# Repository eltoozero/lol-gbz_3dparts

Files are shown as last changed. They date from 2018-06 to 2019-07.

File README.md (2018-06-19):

# Gameboy Zero SCAD 3D prints

This is the SCAD source code for my components for the GBZ project, specifically the Kite's Circuit Sword version.

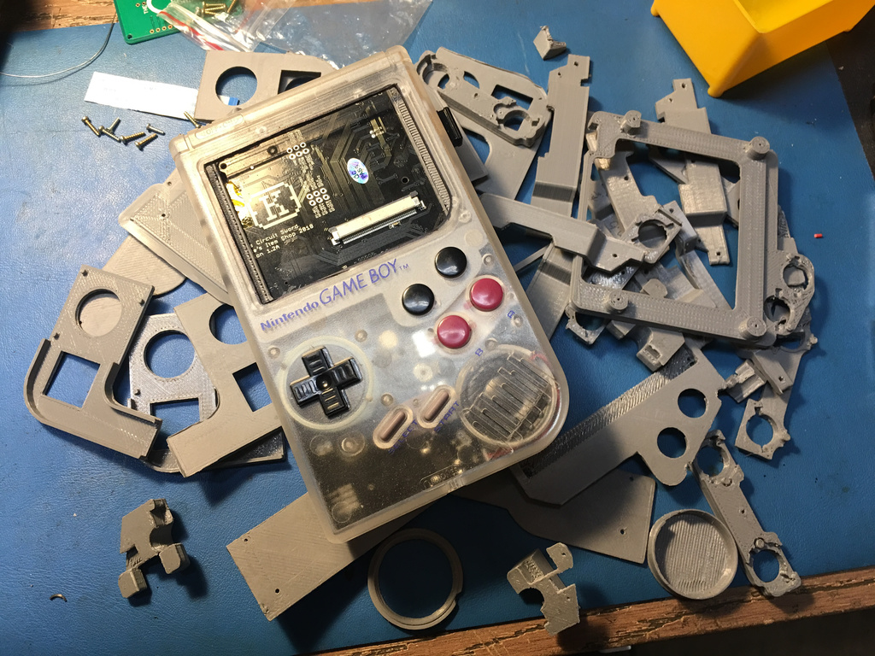
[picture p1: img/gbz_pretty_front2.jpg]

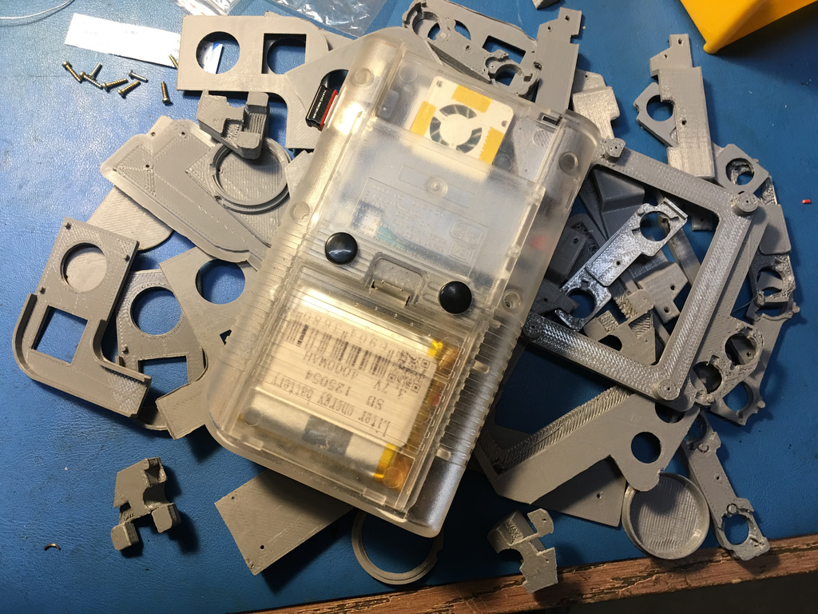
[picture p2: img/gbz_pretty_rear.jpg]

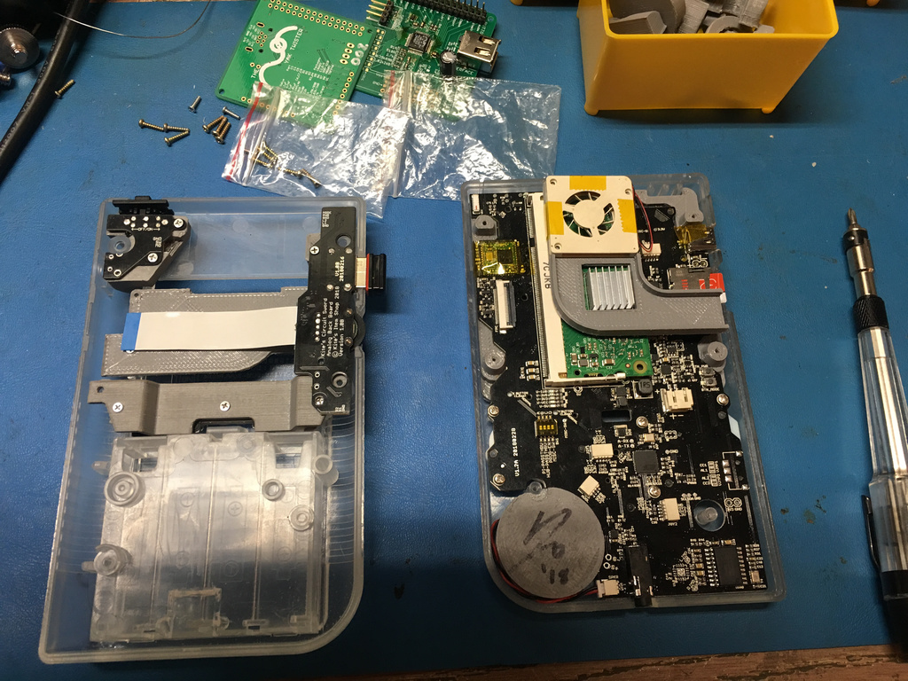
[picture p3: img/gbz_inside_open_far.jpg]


## Notes on SCAD files
I design stuff in SCAD, so my designs are all naturally "parametric" source code and thus can be iterated and modified using the same CSG logic from which they are produced: numeric translations and rotations, intersections, unions and differences of basic 2d and 3d primitives to produce a final "solid" object STL file which is output to the slicer for production on a 3D printer.

It's not going to help anyone to pull these into normal CAD software and make changes, if you want to "help", learn SCAD and fork the source; witness the [Genealogy of the "Greg's Wade's Geared Extruder](https://reprap.org/wiki/Genealogy_/_Archeology_of_the_Greg%27s_Wade%27s_Geared_Extruder) to see what happens when a quality SCAD design can flourish as source code.

## LCD Bracket
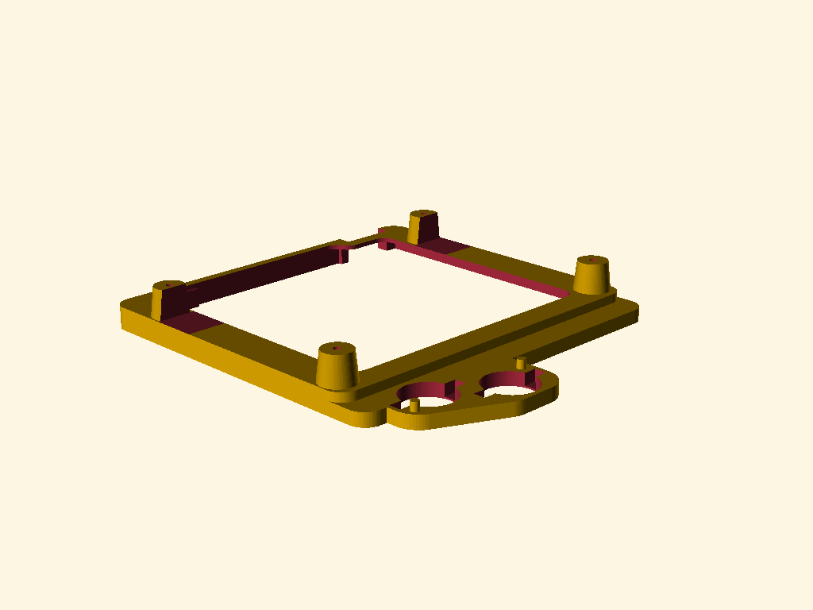
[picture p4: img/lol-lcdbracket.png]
LCD Bracket Image

There were some contours that didn't jive with me, and since I'm doing a clear build I desired more control over the final product, this one was pretty easy and only took two prototypes to get a functional part I was satisfied with.
 - Needs the other two buttons added, should be trivial, I only wanted 4 on my build.

## Back Button Bracket
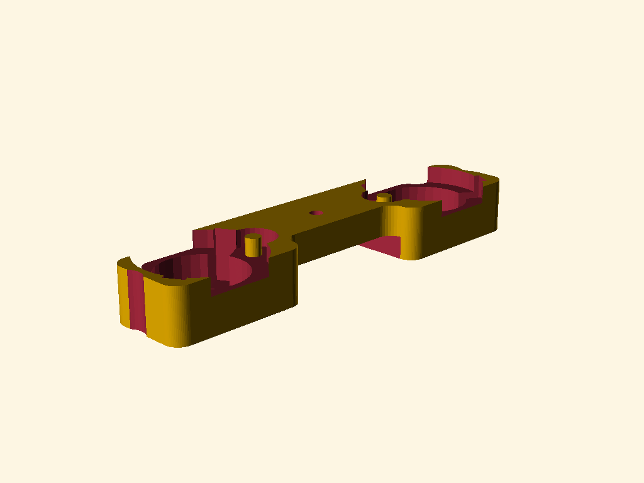
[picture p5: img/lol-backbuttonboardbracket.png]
Back Button Bracket Image

I actually emailed Kite for some info on the components the pcb was designed around that wasn't in the wiki, once it was clear it's not really a solved problem how this thing is installed in the case, I got to work. This took maybe a dozen revisions to get right, in the end it functions glue-less using the support bracket that also supports the back board.
 - Needs additional versions for 4-button and tact switch configs, I need reference parts to do this.

## Back Button Support
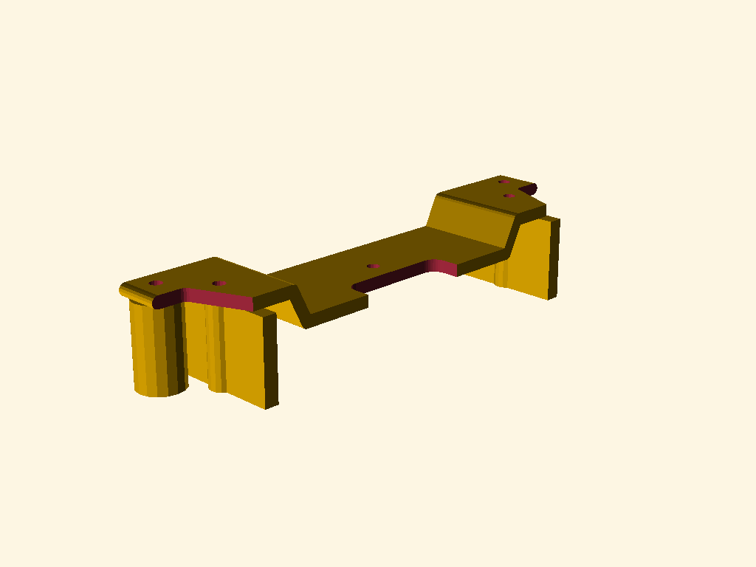
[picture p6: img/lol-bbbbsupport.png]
Back Button Support Image

This one was tricky, and I'm the least satisfied with this design aesthetically, but it prints well and functions for it's purpose, also keeps the entire cartridge slot intact and unmodified.
 - Make it look less crappy.
 - Needs relief for wiring.

## Speaker Cover
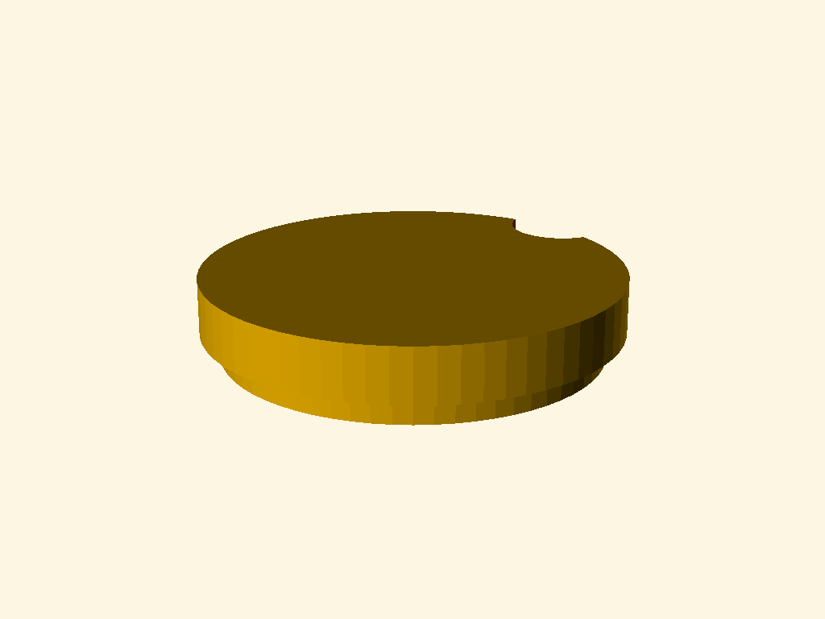
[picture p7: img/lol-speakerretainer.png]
Speaker Cover Image

Simple, I just didn't like the concept of gluing the speaker, and the tolerances are correct that this just press fits and stays snug once the case is closed.

## Power Board Support
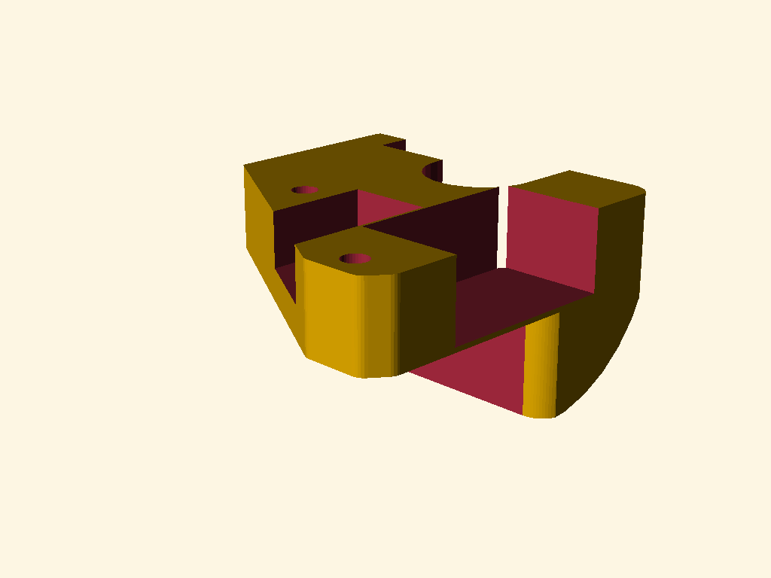
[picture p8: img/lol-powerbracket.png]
Power Board Support Image

Different approach than HoolyHoo, single part solution.

## Back Board Support
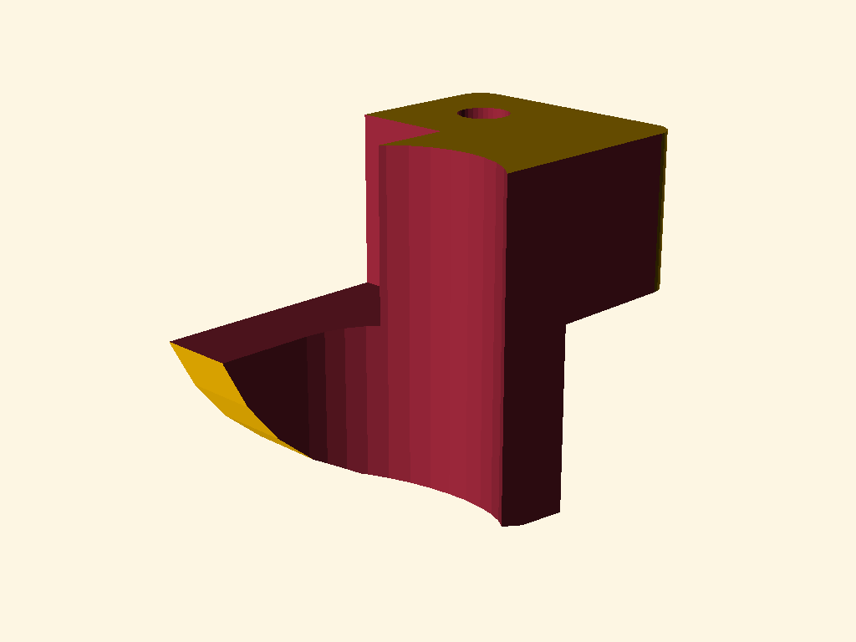
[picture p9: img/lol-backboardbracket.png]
Back Board Support Image

Hadn't seen this one and it's a basic variation of the otherwise much more complicated: Power Board Support.

## Cartridge Plate & Fan Duct
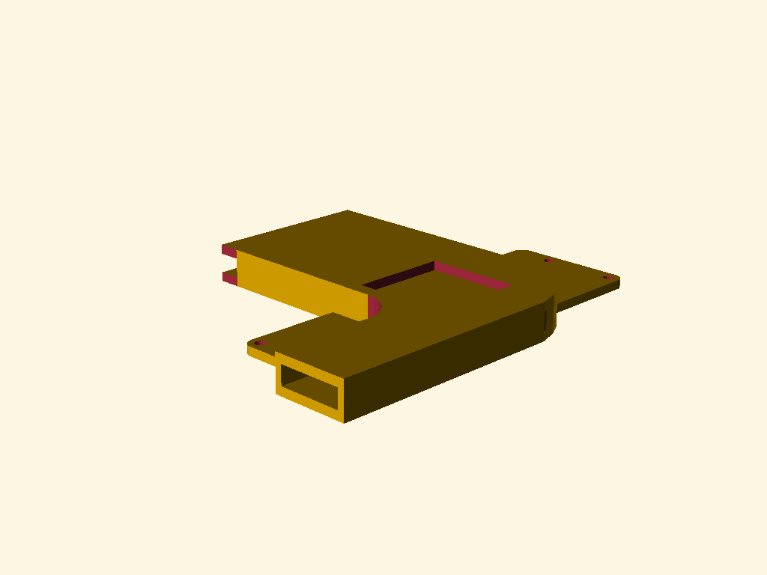
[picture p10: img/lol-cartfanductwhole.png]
Fan Duct Image

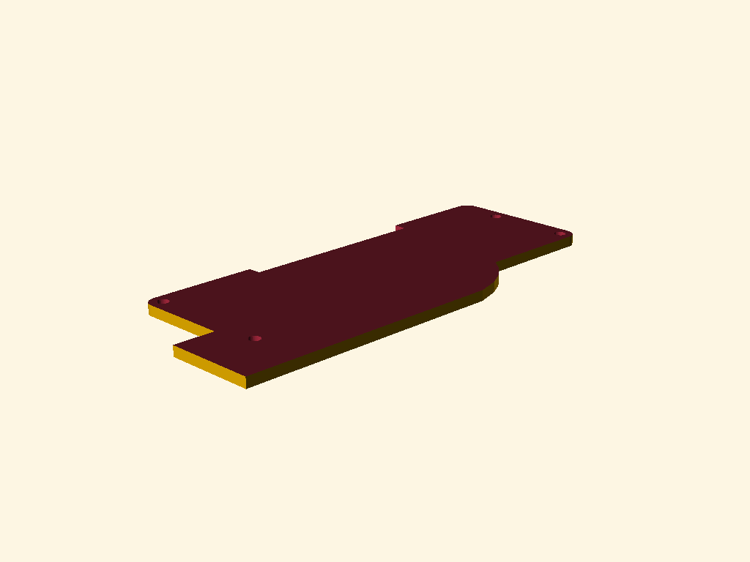
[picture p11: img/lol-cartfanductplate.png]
Fan Duct Plate Image

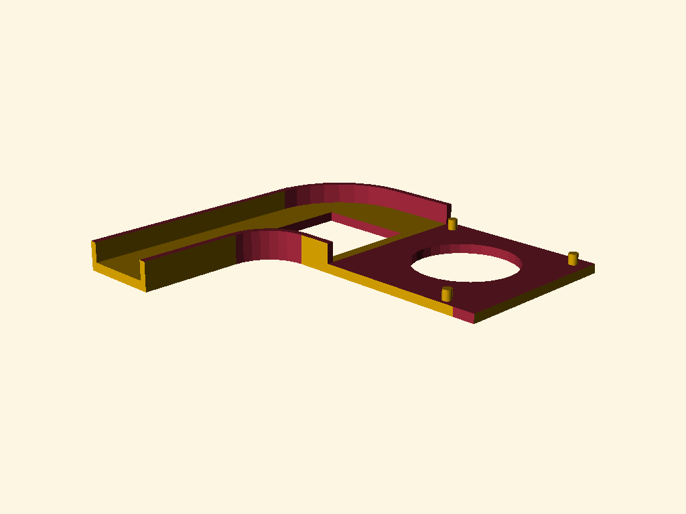
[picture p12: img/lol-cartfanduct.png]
Fan Duct Image

This guy took some thought and effort, and only functions as cleanly as it turned out due to luck, the tolerances are super tight. Kapton or double-sided tape the fan to the support bracket, then use a double stack of 3M VHB to hold the duct in place on the CM3.
 - I'm "exhausted" working on this one.
 - There's probably some optimization potential though.

I'll be selling these parts on eBay and sudomod once I get the extruder upgraded on my "other" 3D printer, these are fine for personal use but please don't sell them unless I'm not, further you are free and encouraged to modify these designs as long as I retain credit and am not artificially restricted from production and sale of designs based on my source code.

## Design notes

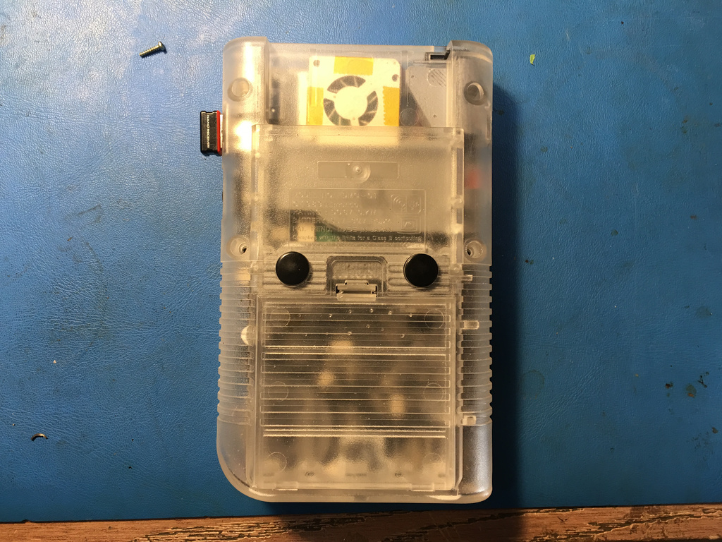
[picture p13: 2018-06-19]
img/gbz_closed_rear.jpg

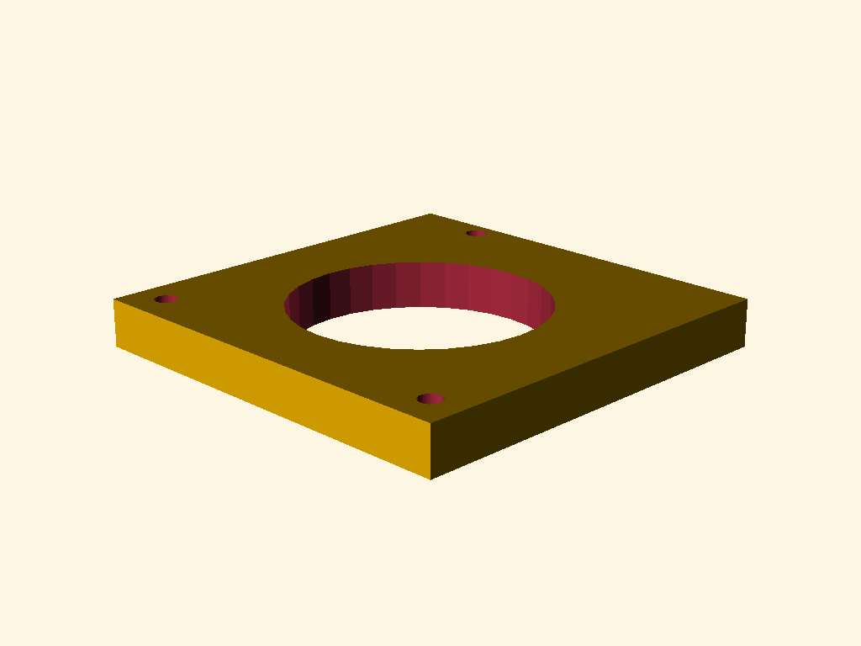
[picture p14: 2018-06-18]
img/lol-fanmockup.png

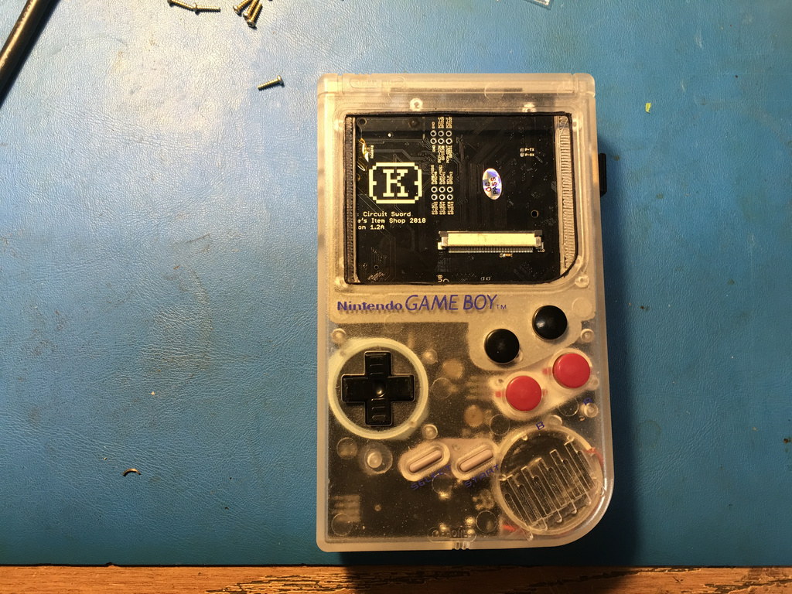
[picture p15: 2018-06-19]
img/gbz_closed_front.jpg

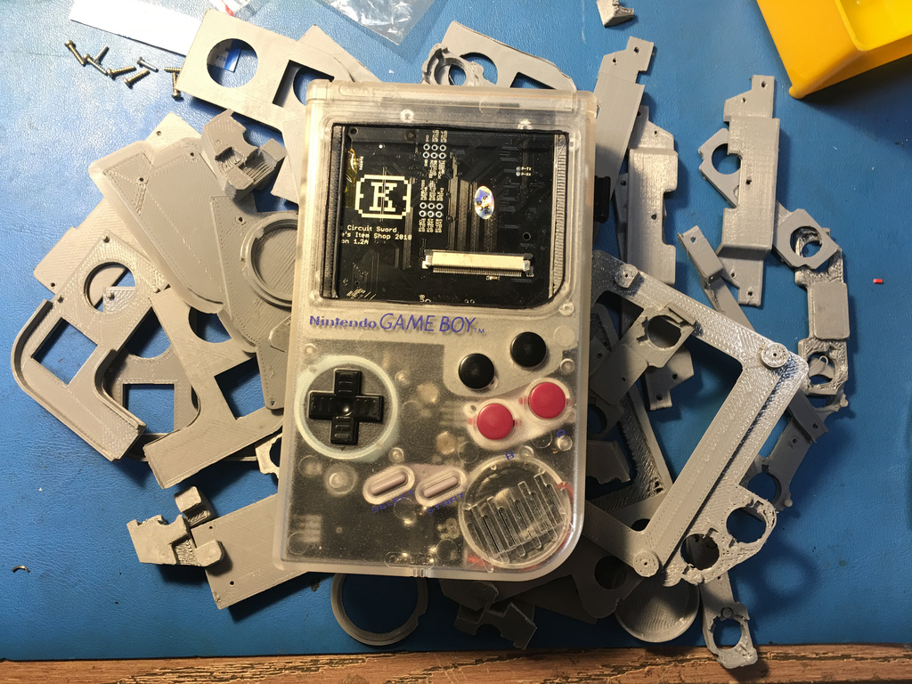
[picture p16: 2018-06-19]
img/gbz_pretty_front.jpg

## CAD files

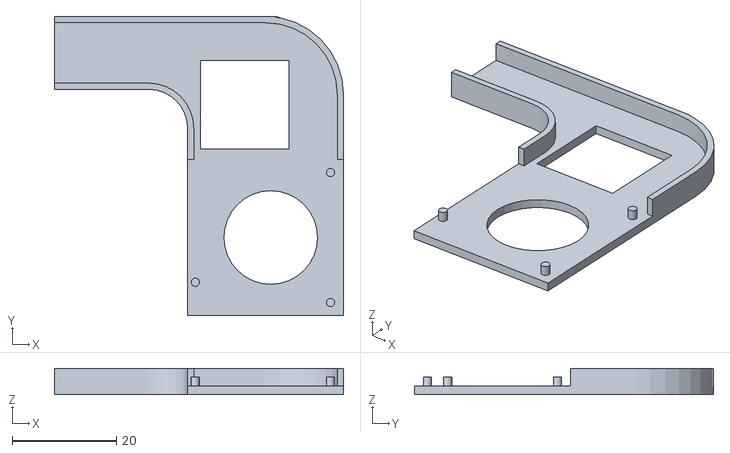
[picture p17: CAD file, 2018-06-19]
stls/lol-cartfanductwhole.stl
55.6 x 57.5 x 5.00

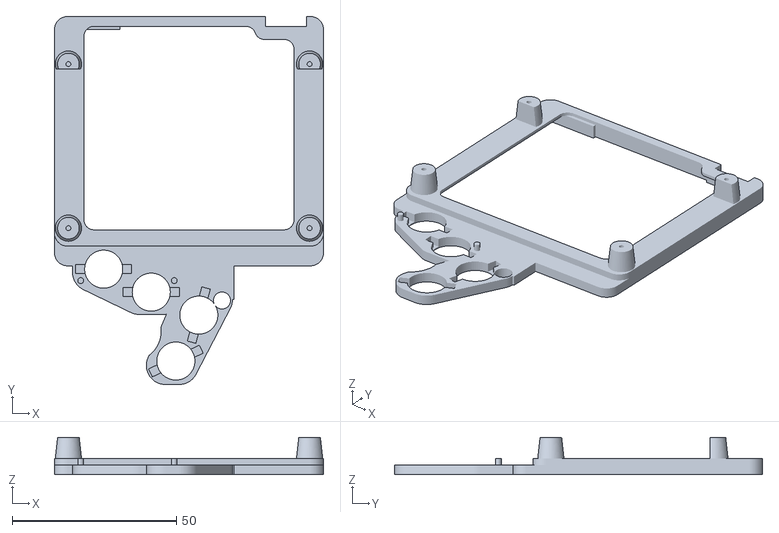
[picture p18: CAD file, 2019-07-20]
stls/lol-lcdbracket_6button.stl
82.0 x 112.2 x 11.4

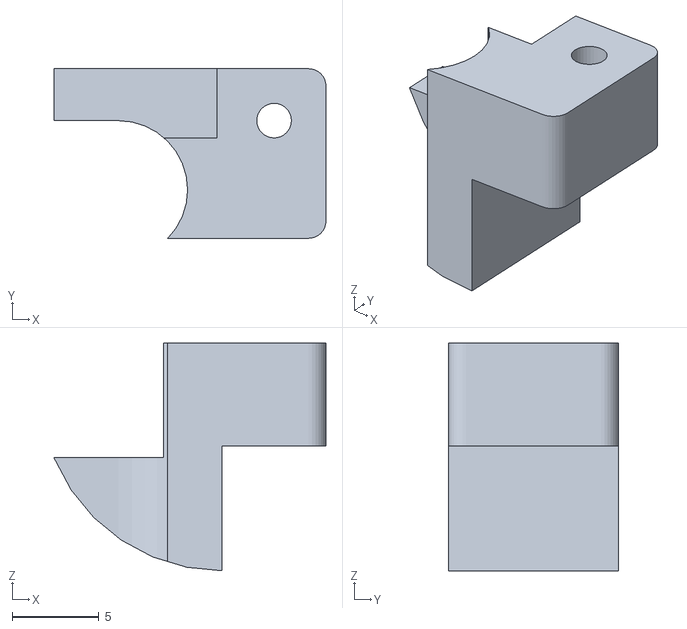
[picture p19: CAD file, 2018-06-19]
stls/lol-backboardbracket.stl
15.7 x 9.80 x 13.2

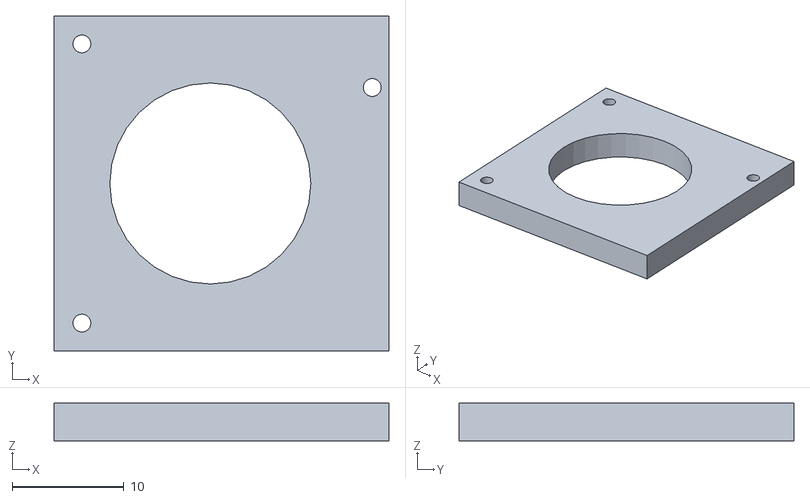
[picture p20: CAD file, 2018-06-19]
stls/lol-fanmockup.stl
30.0 x 30.0 x 3.40

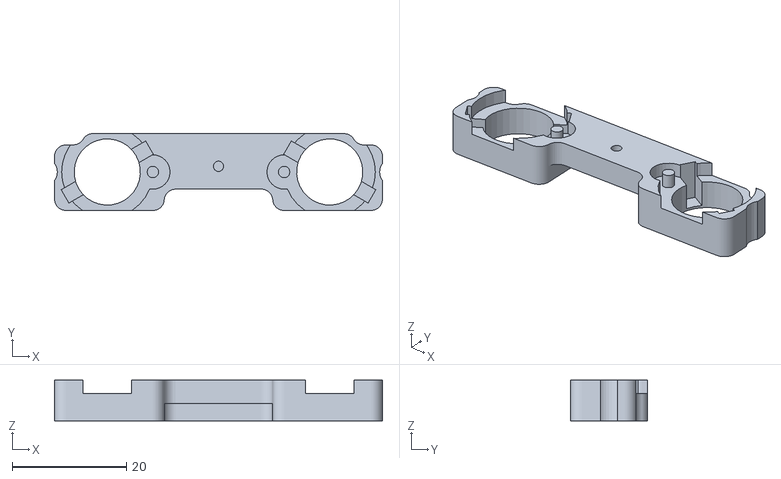
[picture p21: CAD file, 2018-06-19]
stls/lol-backbuttonboardbracket.stl
57.5 x 13.5 x 7.10

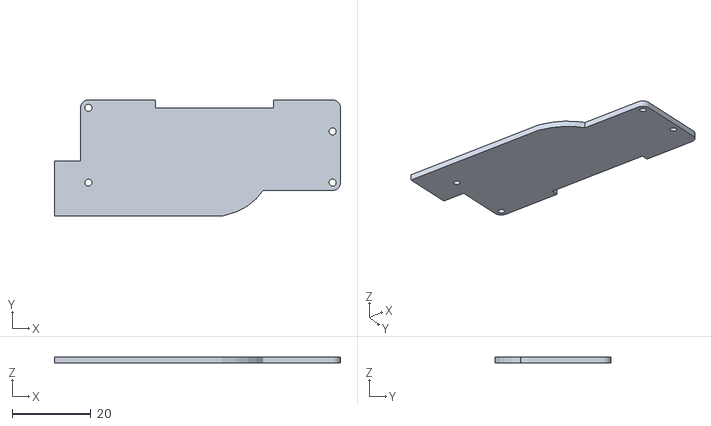
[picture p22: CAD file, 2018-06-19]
stls/lol-cartfanductplate.stl
72.6 x 29.5 x 1.60

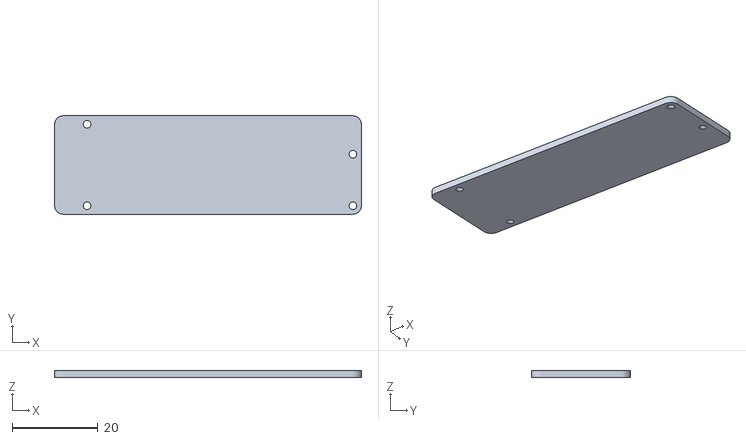
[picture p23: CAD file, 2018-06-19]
stls/lol-cartfanplate.stl
71.6 x 23.0 x 1.60

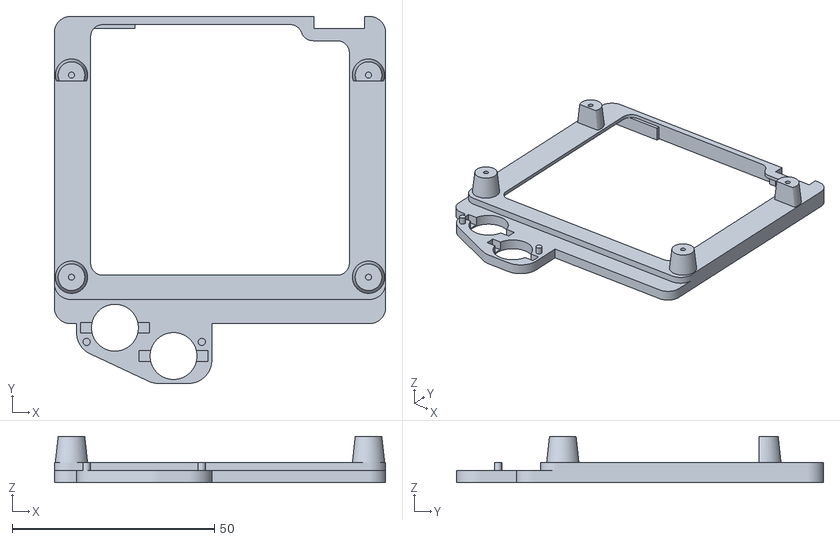
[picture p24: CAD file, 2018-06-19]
stls/lol-lcdbracket.stl
82.0 x 90.8 x 11.4

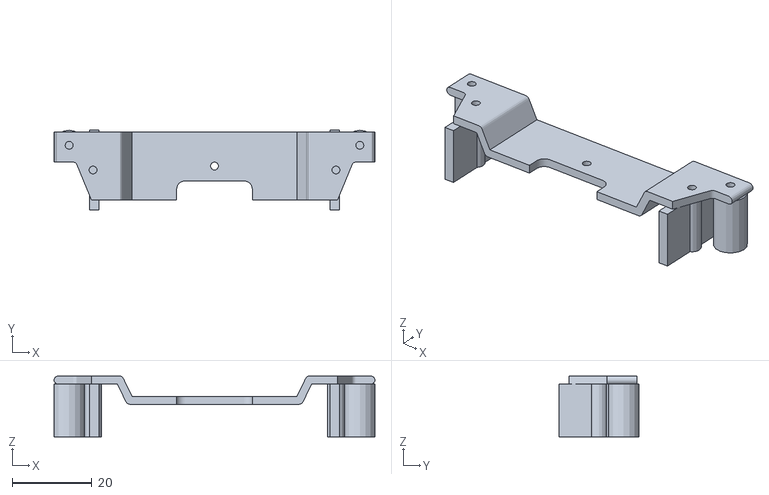
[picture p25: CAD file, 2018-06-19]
stls/lol-bbbbsupport.stl
80.6 x 20.0 x 15.3

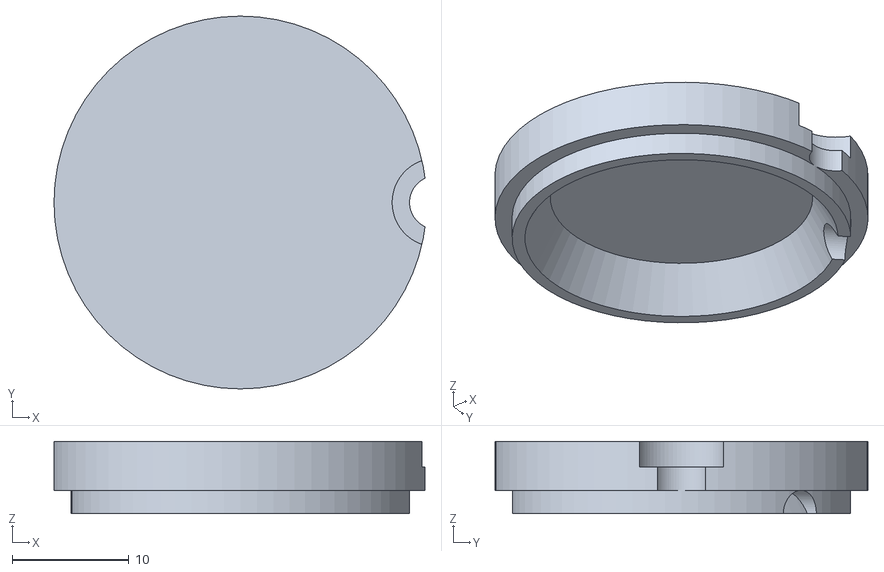
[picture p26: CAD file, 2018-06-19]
stls/lol-speakerretainer.stl
31.8 x 32.0 x 6.20

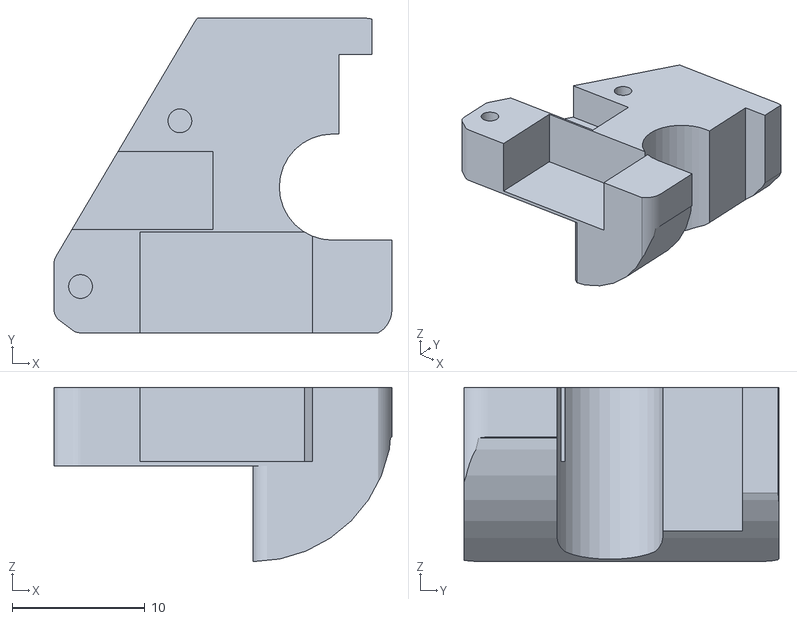
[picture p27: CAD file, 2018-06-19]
stls/lol-powerbracket.stl
25.5 x 23.8 x 13.2

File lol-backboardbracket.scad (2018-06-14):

//lol here's a power/mode button support

//notes from mvp print:
//-cut entire front face for mode button
//-add 1mm fudge room around parts.
//-add a 1mm z depth to connectors
//-remove 2.2mm from the extension "height".

//notes from mvp2 print:
//-still need 2.2mm extra thickness on support.

$fn=32;

// hclearance left of cartridge area inside shell
// measured 10.75mm

pcbclearance=1.1;
hclearance=10.5;
vclearance=14.25;
stackclearance=7.2;

supportplatethickness=vclearance-pcbclearance-stackclearance;
vsupport=(supportplatethickness+hclearance)-vclearance;
echo(supportplatethickness);
echo(vsupport);

//translate([-modex,-10,-vclearance])
//color("blue") cube([modex,modey,vclearance]);
//
//translate([-modex,modey-10,-vclearance])
//color("red") cube([10,10,stackclearance]);

// peg keepout
//D measured 7.58mm
pegD=8;
//Inset measured ~ 4.88mm
pegI=4.5;
//Y
pegY=11;

//mode board
// H
modey=24;
// W
modex=25.5;
// no mount
modexnoflag=21;

noflag=true;

//mode button itself
// H
mbuttx=4;
// W
mbutty=6.5;
// D
mbuttz=vclearance;

//face clearance
facecw=10.5;
facech=7;

// Power Switch
//H
pswz=5.6;
//W measured 12.69mm
pswx=13;
//D 
pswy=7.5;
//Offset
mswo=6;

//Connector
//H
mconz=3.7;
//W
mconx=4.4;
//D
mcony=5.4+.5;
//X Offset
mconox=13.5;
//Y Offset
mconoy=7.8;

//Mounting holes
md=1.8;
//Top X
tx=23.5;
//Top Y
ty=3.5;
//Bot X
bx=16;
//Bot Y
by=16;

//Back board mount hole

bbmx=9;
bbmy=4;

//Back board ports

usbx=10.2;
usby=14.6;
usbz=6.6;

swconx=4.4;
swcony=8.2;
swconz=3.2;

module usbcut() {
    translate([0,pegY+pegD/2-1,-usbz-pcbclearance])
    cube([usbx,usby,usbz]);
}

module swconcut() {
    translate([0,0,-swconz-pcbclearance-vclearance])
    cube([swconx+hclearance+3, swcony, swconz+vclearance]);
}

module backboard_mount() {
    translate([pegI+bbmx,pegY+bbmy,-vclearance])
    cylinder(d=2,h=vclearance);
}

//base_shape();

final_part();

//post placement
//translate([-hclearance,modey+3,-vclearance-pcbclearance])
//cylinder(d=2, h=vclearance);

module final_part() {

    intersection(){
difference() {
    base_shape();
    all_cuts();
    backboard_mount();
    swconcut();
    usbcut();
    //cheat
    translate([0,pegY+bbmy+3,0])
    swconcut();
    //base_block();
}
//        union(){
//        over_cut();
//        over_cut_low();
//        
//        }
    }
}

module base_shape() {
    union() {
        base_block();
        smooth_base();
        //support_tab();
    }
}

module over_cut(){
    translate([-modey/2-1,modex/2-1,-supportplatethickness-pcbclearance])
    cheese(modey+2, modey, supportplatethickness, 2);
}

module over_cut_low(){
    translate([-hclearance/2,modex/2-1,-(vclearance-supportplatethickness-pcbclearance)-supportplatethickness-pcbclearance])
    cheese(hclearance, modey, vclearance-supportplatethickness-pcbclearance, 2);
}


module smooth_base() {
    translate([0,0,-supportplatethickness-pcbclearance])
    hull() {
        
    //top left
//    translate([1,1,0])
//#    cylinder(d=2, h=supportplatethickness);

    //bottom left
//    translate([1,modey-1,0])
//    cylinder(d=2, h=supportplatethickness);

    //top left inside step
//    translate([-1-3,1,0])
//    cylinder(d=2, h=supportplatethickness);

    //bottom left inside step
    translate([0,pegY+bbmy+2,0])
    cylinder(d=2, h=supportplatethickness);

    //bottom left inset
    translate([pegI+bbmx,pegY+bbmy,0])
    cylinder(d=2, h=supportplatethickness);

    //bottom left inset
    translate([pegI+bbmx+2,pegY+bbmy+2,0])
    cylinder(d=2, h=supportplatethickness);

    translate([pegI+bbmx+2,swcony+1,0])
    cylinder(d=2, h=supportplatethickness);

    translate([0,swcony+1,0])
    #cylinder(d=2, h=supportplatethickness);

    //top right
    //translate([-modex+1,1,0])
    //cylinder(d=2, h=supportplatethickness);

    //top right new
//    translate([pegI+bbmx+2,1,0])
//    cylinder(d=2, h=supportplatethickness);
//    
    //top right inset
//    translate([-modex+2,1,0])
//    cylinder(d=2, h=supportplatethickness);


    //right 1st attempt
    //translate([-modex+1,pswy,0])
    //#cylinder(d=2, h=supportplatethickness);

    // bottom hole outlines
//    translate([-bx-1,by-pswy/2+2,0])
//    cylinder(d=2, h=supportplatethickness);
//
//    translate([-bx-1,by+pswy/2-2,0])
//    cylinder(d=2, h=supportplatethickness);

    // top hole outlines
//    translate([-tx-1,ty-pswy/2+2,0])
//    cylinder(d=2, h=supportplatethickness);
//
//    translate([-tx-1,ty+pswy/2-2,0])
//    cylinder(d=2, h=supportplatethickness);
        
    //bottom left
//    translate([-1,modey+3,supportplatethickness-3.75])
//    cylinder(d=2, h=3.75);
    //bottom left inside step
//    translate([-1-3,modey+3,0])
//    cylinder(d=2, h=supportplatethickness);

    }
} //end smooth_base module

module support_tab(){
    translate([0,0,-pcbclearance-supportplatethickness-1.2])
    hull() {
        //tab support
        translate([-hclearance,modey+3,0])
        cylinder(d=4, h=1.2);
        
        //bottom left
        translate([-1,modey-1,0])
        cylinder(d=2, h=1.2);
        
        //bottom left inset
        translate([-1-13,modey-1,0])
        cylinder(d=2, h=1.2);
    }
}

module all_cuts() {
    
//    difference() {
//
//    base_block();

    translate([pegI, pegY, -vclearance]){
        //peg clearance
        cylinder(d=pegD, h=vclearance);
        translate([-pegD,-pegD/2,0])
        //peg extension
        cube([pegD,pegD,vclearance]);
    }
        //mode button cut
//        translate([-mbuttx,modey-mbutty-3,-mbuttz-pcbclearance])
//        cube([mbuttx,mbutty,mbuttz]);

        //mode button face cut
        translate([0-1.5,modey-facecw,-facech-4])
        cube([mbuttx/2,facecw+1,facech+4]);

        //power switch
//        translate([-pswx-mswo,-1,-pswz-pcbclearance])
//        cube([pswx, pswy+pcbclearance, pswz]);

        //connector
//        translate([-mconx-mconox-10,mconoy,-mconz-pcbclearance])
//        cube([mconx+10, mcony, mconz+pcbclearance]);
    
        //connector thru
//      translate([-mconx-mconox-10,mconoy,-(vclearance-hclearance+1)])
//        #cube([mconx+10, mcony, vclearance-hclearance+1]);

        //Mounting holes
//        translate([-tx,ty,-supportplatethickness])
//        cylinder(h=supportplatethickness, d=md);
//        translate([-bx,by,-supportplatethickness])
//        cylinder(h=supportplatethickness, d=md);

        //post placement
        translate([-hclearance,modey+3,-vclearance-pcbclearance])
        cylinder(d=1.8, h=vclearance);

//    } // end difference 
} //end rough part


module base_block(){
    translate([hclearance,0,-vclearance+hclearance]) {
    union() {
        rotate([90,0,180])
        difference(){
            cylinder(h=modey, r=hclearance);

            translate([-hclearance,0,0])
            cube([hclearance*2,hclearance*2,modey]);

            translate([-hclearance*2,-hclearance,0])
            cube([hclearance*2,hclearance*2,modey]);
        }
        
        //base plate
//        translate([-modex+hclearance,0,0])
//        cube([modex, modey, vclearance-hclearance]);
//        translate([hclearance,0,0])
        }
    }
}
        

module cheese(x,y,z,r) {
linear_extrude(height=z) offset(-r) offset(r) offset(r) offset(-r)
    square([x,y], center=true);
}

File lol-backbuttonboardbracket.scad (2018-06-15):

$fn=32;

// DMG Rear Body Dimensions
// Above Battery Compartment

// Width measured 58mm 
OuterW=57.5;
// W
LatchW=19;
// Detpth measured .7mm
latchz=1;

//Silicone thickness
silz=2.3;
//Sil diameter
sild=16;

//side post -y from notch bottom
py=5;
// post diameter
pd=5; //measured 4mm, oversizing.

module post_removal() {
    for(x=[-OuterW/2-2:OuterW+4:OuterW/2+2]) {
        translate([x,0,0])
        cylinder(d=pd,h=ExtD+silz);
    }
}


module lil_peg() {
for(i=[-DualButtonSep/2+sild/2:DualButtonSep-sild:DualButtonSep/2-sild/2]) {
    translate([i,0,ExtD])
    cylinder(d=2,h=silz);
}
}
//sil_cut();
module sil_cut() {
for(i=[-DualButtonSep/2:DualButtonSep:DualButtonSep/2]) {
    translate([i,0,ExtD])
    cylinder(d=sild,h=silz);
}

for(i=[-DualButtonSep/2+sild/2:DualButtonSep-sild:DualButtonSep/2-sild/2]) {
    translate([i,0,ExtD])
    cylinder(d=6,h=silz);
}
}

module side_supports(){
    hull() {
        translate([OuterW/2-supd/2,-supd/2-.5,ExtD]){
    translate([0,NotchH/2-2,0])
    cylinder(d=supd, h=silz);
    translate([0,-NotchH/2+2,0])
    cylinder(d=supd, h=silz);
        }
    }
    hull() {
        translate([-OuterW/2+supd/2,-supd/2-.5,ExtD]){
    translate([0,NotchH/2-2,0])
    cylinder(d=supd, h=silz);
    translate([0,-NotchH/2+2,0])
    cylinder(d=supd, h=silz);
        }
    }

}

// H measured at 11.8mm
NotchH=11.5;
// Thickness measured 2.2mm
notchy=2;

// DMG Button Dimensions
// H
ButtonH=10;
// R
ButtonR=5.8;

// DMG Button Flag
// H
FlagH=ButtonH;
// W
FlagW=2.7;
// D
FlagD=5.5;

supd=1.2;

// Button Extension
// H
ExtH=14;
// W
ExtW=29.5;
// D
ExtD=3+1.8;
// Lip
ExtLip=6;

DualButtonSep=39;
//
//translate([-8.5-OuterW/2,18.1,-2])
//rotate([90,0,0])
//import("gbz_KiteBracket.stl");

module backbracketbody2d() {
    difference() {
    union(){
        translate([-OuterW/2,-NotchH/2,0])
        square([OuterW,NotchH]);
        translate([-48/2,NotchH/2])
        square([48,notchy]);
    }
    translate([-LatchW/2,-NotchH/2])
    square([LatchW, 3.75]);
    }
}

module backbracketbody() {
linear_extrude(height=ExtD+silz) offset(-2) offset(2) offset(2) offset(-2)backbracketbody2d();
}

//rotate([0,180,0])
final_part();
module final_part() {
    lil_peg();
    difference(){
    union() {
    //translate([-OuterW/2,-ExtH/2,0])
    //linear_extrude(height=ExtD) offset(2) offset(-2) square([OuterW,ExtH]);

    translate([0,-1,0])
    backbracketbody();
//    side_supports();

//    translate([0,2.75,ExtD])
    //#cube([LatchW, ExtH, latchz], center=true);
//    cheese(LatchW, ExtH-2.75, silz, 2);

//    translate([DualButtonSep/2,7.5,ExtD])    
//    cylinder(d=1.8, h=2.4);
//    translate([-DualButtonSep/2,7.5,ExtD])    
//    cylinder(d=1.8, h=2.4);
    }

    //translate([OuterW/2-10,0,0])
    translate([DualButtonSep/2,0,0])
    rotate([0,0,-30])
    dmgbutton();

    translate([-DualButtonSep/2,0,0])
    rotate([0,0,30])
    dmgbutton();
    post_removal();
    sil_cut();
    //translate([0,0,latchz/2])
    //cube([LatchW, ExtH, latchz], center=true);
    translate([0,-2.5,0])
    cheese(LatchW, ExtH, latchz*3, 2);

    //screw hole
    translate([0,1,4])
    cylinder(d=1.8,h=ExtD+silz);
    }
}

//Button
module dmgbutton(x,y) {
translate([x,y,0])    
    union() {
        cylinder(h=ButtonH, r=ButtonR); 
        translate([-ButtonR,0,FlagH/2+.4])
            cube([FlagD,FlagW,FlagH], center=true);
            translate([ButtonR,0,FlagH/2+.4])
            cube([FlagD,FlagW,FlagH], center=true);
    }
}

module cheese(x,y,z,r) {
linear_extrude(height=z) offset(-r) offset(r) offset(r) offset(-r)
    square([x,y], center=true);
}

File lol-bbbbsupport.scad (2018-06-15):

//lol-bbbbsupport

$fn=16;

//button board bracket clearance
bbcz=6.4;

//slot clearance
slcz=8.2;





// Mounting Posts Case
// Diameter
cmd=7.6;
// Height
cmz=13.3;
// OffsetY
cmoy=2.7+.5;
// OffsetX
cmox=74-1;
// Hole Diameter
cmhd=2;

// Mounting Posts PCB
// Diameter
pmd=4.2;
// Height
pmz=13.3;
// OffsetY
pmoy=-4+1;
// OffsetX
pmox=62-1;
// Hole Diameter
pmhd=2;


//Post Y Distance 
//12.6 - 4.2/2 - 7.6/2
//12.6 - 2.1 - 3.8
//12.6 - 5.9
// 6.7

// Width measured 58.5mm 
OuterW=58;
// W
LatchW=19;
// Detpth measured .7mm
LatchD=1;
NotchW=53;
NotchX=OuterW-NotchW;

latchcx=14;

// H measured at 11.8mm
notchh=11.5;
// Thickness measured 2.2mm
notcht=2.4;
notchy=3.75;

// Other Parameters
//main thickness
pt=2;

//post offset y
poy=6.7;

//overall y dimension
oy=17;

//translate([0,3,0])
//mounting_posts();
//walls();
//translate([0,0,0])
//import("lol-backbuttonboardbracket.stl");

module walls() {
for (x=[-OuterW/2-notcht/2:OuterW+notcht:OuterW/2+notcht/2])
translate([x,0,pmz/2])
cube([notcht, 20, pmz], center=true);
}

module connector_cut() {
    hull() {
    translate([cmox/2+10,0,0])
    cylinder(d=2,h=pmz+pt);
    translate([cmox/2-1,0,0])
    cylinder(d=2,h=pmz+pt);
    translate([cmox/2-notchh/2,-notchh,0])
    cylinder(d=2,h=pmz+pt);
    translate([cmox/2+10,-notchh,0])
    cylinder(d=2,h=pmz+pt);
    }
}


module notch_cut2() {
    translate([0,-notchy*2,slcz])
    cheese(LatchW,3.75*2,pt,2);

}
//notch cut
//notch_cut();
module notch_cut(){
    hull(){
    
    translate([0,-oy/2+notchy/2,0]){
        translate([-latchcx/2,0,0])
        cylinder(d=notchy, h=pmz);
        translate([latchcx/2,0,0])
        cylinder(d=notchy, h=pmz);
    }
    translate([0,-oy/2-notchy/2,0]){
        translate([-LatchW/2,0,0])
        cylinder(d=notchy, h=pmz);
        translate([LatchW/2,0,0])
        cylinder(d=notchy, h=pmz);
    }

    }
}

module screw_cut(){
translate([0,1,0])
cylinder(d=2, h=pmz);
//    hull(){
//    
//    translate([0,-oy/2+notchy/2+4,0]){
//        translate([-latchcx/2+4,0,0])
//        cylinder(d=notchy, h=pmz);
//        translate([latchcx/2-4,0,0])
//        cylinder(d=notchy, h=pmz);
//    }
//    translate([0,-oy/2-notchy/2+4,0]){
//        translate([-LatchW/2+4,0,0])
//        cylinder(d=notchy, h=pmz);
//        translate([LatchW/2-4,0,0])
//        cylinder(d=notchy, h=pmz);
//    }
//
//    }
}


//mounting post stand ins
module mounting_posts() {
    //PCB Mount posts
    //left
    translate([-pmox/2, pmoy, 0])
    cylinder(d=pmd, h=pmz);
    //right
    translate([pmox/2, pmoy, 0])
    cylinder(d=pmd, h=pmz);

    //Case Mount posts
    //left
    translate([-cmox/2, cmoy, 0])
    cylinder(d=cmd, h=cmz);
    //right
    translate([cmox/2, cmoy, 0])
    cylinder(d=cmd, h=cmz);
}

//mounting_holes();
module mounting_holes() {
    //PCB Mount posts
    //left
    translate([-pmox/2, pmoy, 0])
    cylinder(d=pmhd, h=pmz+pt);
    //right
    translate([pmox/2, pmoy, 0])
    cylinder(d=pmhd, h=pmz+pt);

    //Case Mount posts
    //left
    translate([-cmox/2, cmoy, 0])
    cylinder(d=cmhd, h=cmz+pt);
    //right
    translate([cmox/2, cmoy, 0])
    cylinder(d=cmhd, h=cmz+pt);
}

//print orientation
rotate([-90,0,0])
translate([0,1,0])
final_part();
module final_part() {
difference() {
    base_bracket();
    notch_cut2();
translate([0,-1,0])
    screw_cut();
    translate([0,2,0])
    mounting_holes();
    connector_cut();
mirror() connector_cut();
    
    
}
}
//base_bracket();
module base_bracket() {
union() {
    left_side();
    right_side();
    bottom_part();
    top_left();
    top_right();

}
}

//bottom part
module bottom_part() {
    hull() {
        //bottom right
        node(pmox/2-pmd-NotchX,0,pt/2+slcz);
        //bottom left
        node(-pmox/2+pmd+NotchX,0,pt/2+slcz);
    }
}

//left side part
module left_side(){
    hull() {
    //top inside left
    node(-pmox/2+pmd+NotchX/2,0,pmz+pt/2);
    //bottom left
    node(-pmox/2+pmd+NotchX,0,pt/2+slcz);
    }
}

//right side part
module right_side(){
    hull() {
    //top right
    node(pmox/2-pmd-NotchX/2,0,pmz+pt/2);
    //bottom right
    node(pmox/2-pmd-NotchX,0,pt/2+slcz);
    }
}

module top_left() {
    hull() {
    //top outside left
    node(-cmox/2-cmd/2+1,0, cmz+pt/2);
    //top inside left
    node(-pmox/2+pmd+NotchX/2,0,pmz+pt/2);
    }
}

//translate([0,0,0])
//#hull() {
//    translate([-pmox/2, pmoy, pmz])
//    color("red") cylinder(d=pmd, h=pt);
//
//    translate([-cmox/2, cmoy, cmz])
//    color("red") cylinder(d=cmd, h=pt);
//
//    node(-pmox/2+pmd+NotchX/2,0,pmz+pt/2);
//}

//translate([0,3,0])
//flap_mount();
//mounting_holes();
module mounting_holes() {
    //PCB Mount posts
    //left
    translate([-pmox/2, pmoy, 0])
    cylinder(d=pmhd, h=pmz+pt);
    //right
    translate([pmox/2, pmoy, 0])
    cylinder(d=pmhd, h=pmz+pt);

    //Case Mount posts
    //left
    translate([-cmox/2, cmoy, 0])
    cylinder(d=cmhd, h=cmz+pt);
    //right
    translate([cmox/2, cmoy, 0])
    cylinder(d=cmhd, h=cmz+pt);
}

module flap_left() {
    hull() {
        //pcb
        //left
        translate([-pmox/2, pmoy+3, pmz])
        cylinder(d=pmd, h=pt);
        //angle
        translate([-pmox/2, -oy/2+pmd/2+1, pmz])
        #cylinder(d=pmd, h=pt);
        
        //case
        //left
        translate([-cmox/2, cmoy+3, pmz])
        cylinder(d=cmd, h=pt);
        //top inside left
        node(-pmox/2+pmd+NotchX/2,1,pmz+pt/2);
    }
}
module top_right() {
    hull() {
    //top outside left
    node(cmox/2+cmd/2-1,0, cmz+pt/2);
    //top inside left
    node(pmox/2-pmd-NotchX/2,0,pmz+pt/2);
    }
}

module node(x,y,z) {
    translate([x,y,z]){
        rotate([90,0,0])
        translate([0,0,-oy/2])
        cylinder(h=oy, d=pt);
        } // end translate wrapper
}

module cheese(x,y,z,r) {
linear_extrude(height=z) offset(-r) offset(r) offset(r) offset(-r)
    square([x,y], center=true);
}

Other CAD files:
stls/lol-cartfanduct.stl
lol-cartfanduct.scad
lol-fanmockup.scad
lol-lcdbracket.scad
lol-powerbracket.scad
lol-speakerretainer.scad

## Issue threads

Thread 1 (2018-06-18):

Fix relief on Power Bracket

eltoozero, 2018-06-18:
Add some kind of cut for the fillet on the USB connector so you don't have to trim after printing.

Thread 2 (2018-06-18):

Fix the horizontal offset of the top holes on the fan duct plate.

eltoozero, 2018-06-18:
I just noticed they are not in fact parallel vertically with the bottom mounts, go see for yourself.

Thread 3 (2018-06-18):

Make relief for analog volume on Back Board Support

eltoozero, 2018-06-18:
This is tough given the orientation of the part, I've got some ideas but it's WIP, I'd rather not just cut it after printing but that's an option.

I guess I could also make it sort of a "breakaway" thing with some mouse nibbles that are easy to trim since the cutout is not required for the HDMI bracket.

maxtato, 2018-10-08:
Hi Lee,
I just received the kite Circuit Sword and I’m very interested by your brackets.
How can I buy one ?
You can answer me at :
max.tato@hotmail.fr
Thanks

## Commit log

2018-06-09 temp measurements and button module
    [lol-lcdbracket.scad]
2018-06-09 added bracket body
    [lol-lcdbracket.scad]
2018-06-10 added lcd cutout and difference modules
    [lol-lcdbracket.scad]
2018-06-10 added more stuff
    [lol-lcdbracket.scad]
2018-06-10 mvp before actual measurements
    [lol-lcdbracket.scad]
2018-06-10 button bracket start
    [lol-lcdbracket.scad]
2018-06-10 button bracket mostly done
    [lol-lcdbracket.scad]
2018-06-10 mostly done
    [lol-lcdbracket.scad]
2018-06-10 dome retention
    [lol-lcdbracket.scad]
2018-06-10 more changes
    [lol-lcdbracket.scad]
2018-06-10 post-fist-print tweaks
    [lol-lcdbracket.scad]
2018-06-11 initial commit of backbuttonboardbracket
    [lol-backbuttonboardbracket.scad, lol-lcdbracket.scad]
2018-06-12 added power bracket
    [lol-powerbracket.scad]
2018-06-12 check-in all scad files
    [lol-backbuttonboardbracket.scad]
2018-06-12 check-in power button
    [lol-powerbracket.scad]
2018-06-12 mvp power bracket
    [lol-powerbracket.scad]
2018-06-12 tweaks after 2 prints
    [lol-powerbracket.scad]
2018-06-13 ready for 3rd print
    [lol-powerbracket.scad]
2018-06-13 speaker bracket added
    [lol-speakerretainer.scad]
2018-06-13 check in all scad files
    [lol-powerbracket.scad]
2018-06-13 speaker thing works
    [lol-speakerretainer.scad]
2018-06-14 bracket added
    [lol-bbbbsupport.scad]
2018-06-14 check in other changes
    [lol-backbuttonboardbracket.scad]
2018-06-14 bunch of changes and optimizations
    [lol-backboardbracket.scad, lol-backbuttonboardbracket.scad, lol-bbbbsupport.scad]
2018-06-15 scad checkin
    [lol-backbuttonboardbracket.scad, lol-bbbbsupport.scad]
2018-06-16 fan duct
    [lol-cartfanduct.scad]
2018-06-17 fan duct fixes
    [lol-cartfanduct.scad]
2018-06-18 lcd bracket fixes
    [lol-lcdbracket.scad]
2018-06-19 added stls
    [lol-backboardbracket.stl, lol-backbuttonboardbracket.stl, lol-bbbbsupport.stl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]
2019-04-14 Add 6-button mode.
    [lol-lcdbracket.scad]
2019-04-14 Replace ExtW and ExtH with the new button arrays.
    [lol-lcdbracket.scad]
2019-04-14 A little more cleanup.
    [lol-lcdbracket.scad]
2019-04-14 Adjustments made from real prints.
    [lol-lcdbracket.scad]
2019-04-14 Add STL
    [lol-lcdbracket_6button.stl]
2019-04-21 tweaks 2
    [lol-lcdbracket.scad]
2019-04-21 Final tweaks.
    [lol-lcdbracket.scad, lol-lcdbracket_6button.stl]
